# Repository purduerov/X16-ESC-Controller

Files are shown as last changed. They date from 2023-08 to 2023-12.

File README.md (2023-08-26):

# Readme for X16-ESC-Controller
This board turns signals from the Pi into PWM signals that go to the ESC Adapter

Whenever you make a new part, download the datasheet and save it here _**and**_ with the part in the parts library

Always pull other people's changes before beginning to work
`git pull`

Be sure to push your changes after  working on them. Run:
1. `git add .` to add any files in this directory or a subdirectory
or `git add -u` to add any modified files
2. (Optional) `git clean -nX` to see what ignored files can be removed
	`git clean -fX` removes ignored files (Eagle backups)
3. `git commit -m "helpful commit message"` with a description of the work that you did
4. `git push` to push your work to github

Other helpful commands
* `git status` says information about modified and staged files
* `git log` shows the recent commits of the repository
* `git log filename.extension` show the recent commits for just that file
* `git checkout first-couple-letter-of-commit-id` lets you go back to a previous version
* `git checkout master` brings you back to the latest commit
* `git tag` lists the tags
* `git tag -a orderX -m "the version of the board placed for the X'th order"` tag a specific commit
* `git push --tags` needed to push tags to remote
* `git show orderX` show the commit log for the given tag
* `git checkout orderX` go back and interact with the files at the tagged commit

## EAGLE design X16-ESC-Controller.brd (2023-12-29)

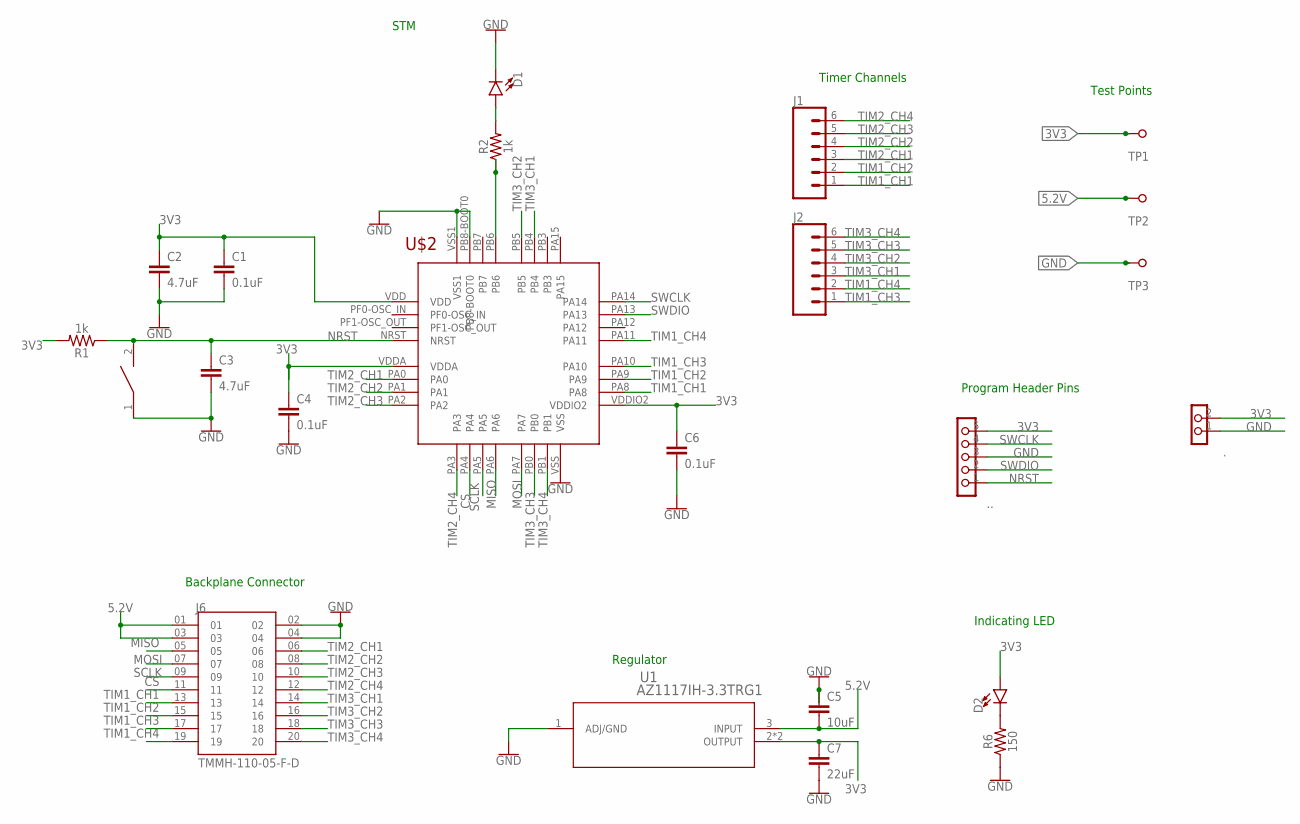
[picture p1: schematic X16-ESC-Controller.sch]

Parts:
.: TEST_PIN-1X2; 1X02
..: TEST_PIN-1X5; 1X05
C1, C4, C6: 0.1uF; 0603
C2, C3: 4.7uF; 0603
C5: 10uF; 0603
C7: 22uF; 0603
D1, D2: Green; LED-0805
J1, J2: CONN_06NO_SILK_NO_POP; 1X06_NO_SILK
J6: TMMH-110-05-F-D; SAMTEC_TMMH-110-05-F-D
R1, R2: 1k; 0603
R6: 150; 0603
TP1, TP2, TP3: TESTPOINT_5.04MM
U1: AZ1117IH-3.3TRG1; SOT223_AZ1117I_6P5X3P5_DIO
U$2: IC_STM32F042K6T6; STM32F042K6T6
U$3: SWITCH_DISCRETECOMPONENTS; DISCRETECOMPONENTS_SW_2512

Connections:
3V3: ..2, ...5, C1.1, C2.1, C4.1, C6.1, C7.1, D2.A, R1.2, TP1.TP, U1.2 (OUTPUT), U1.4 (OUTPUT), U$2.VDD, U$2.VDDA, U$2.VDDIO2
5.2V: C5.2, J6.01, J6.03, TP2.TP, U1.3 (INPUT)
CS: J6.11, U$2.PA4
GND: ..1, ...3, C1.2, C2.2, C3.2, C4.2, C5.1, C6.2, C7.2, D1.C, J6.02, J6.04, R6.1, TP3.TP, U1.1 (ADJ/GND), U$2.PB8-BOOT0, U$2.VSS, U$2.VSS1, U$3.1
MISO: J6.05, U$2.PA6
MOSI: J6.07, U$2.PA7
unnamed: D2.C, R6.2
unnamed: R2.1, U$2.PB6
unnamed: D1.A, R2.2
NRST: ...1, C3.1, R1.1, U$2.NRST, U$3.2
SCLK: J6.09, U$2.PA5
SWCLK: ...4, U$2.PA14
SWDIO: ...2, U$2.PA13
TIM1_CH1: J1.1, J6.13, U$2.PA8
TIM1_CH2: J1.2, J6.15, U$2.PA9
TIM1_CH3: J2.1, J6.17, U$2.PA10
TIM1_CH4: J2.2, J6.19, U$2.PA11
TIM2_CH1: J1.3, J6.06, U$2.PA0
TIM2_CH2: J1.4, J6.08, U$2.PA1
TIM2_CH3: J1.5, J6.10, U$2.PA2
TIM2_CH4: J1.6, J6.12, U$2.PA3
TIM3_CH1: J2.3, J6.14, U$2.PB4
TIM3_CH2: J2.4, J6.16, U$2.PB5
TIM3_CH3: J2.5, J6.18, U$2.PB0
TIM3_CH4: J2.6, J6.20, U$2.PB1

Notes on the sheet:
Timer Channels
Program Header Pins
Indicating LED
Regulator
Test Points
Backplane Connector
STM

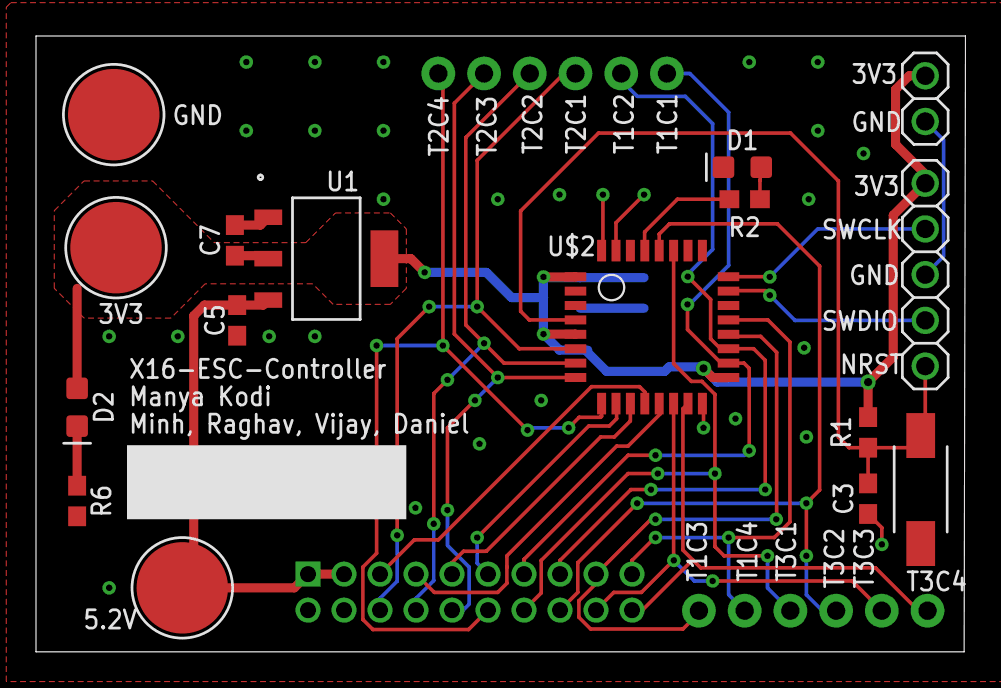
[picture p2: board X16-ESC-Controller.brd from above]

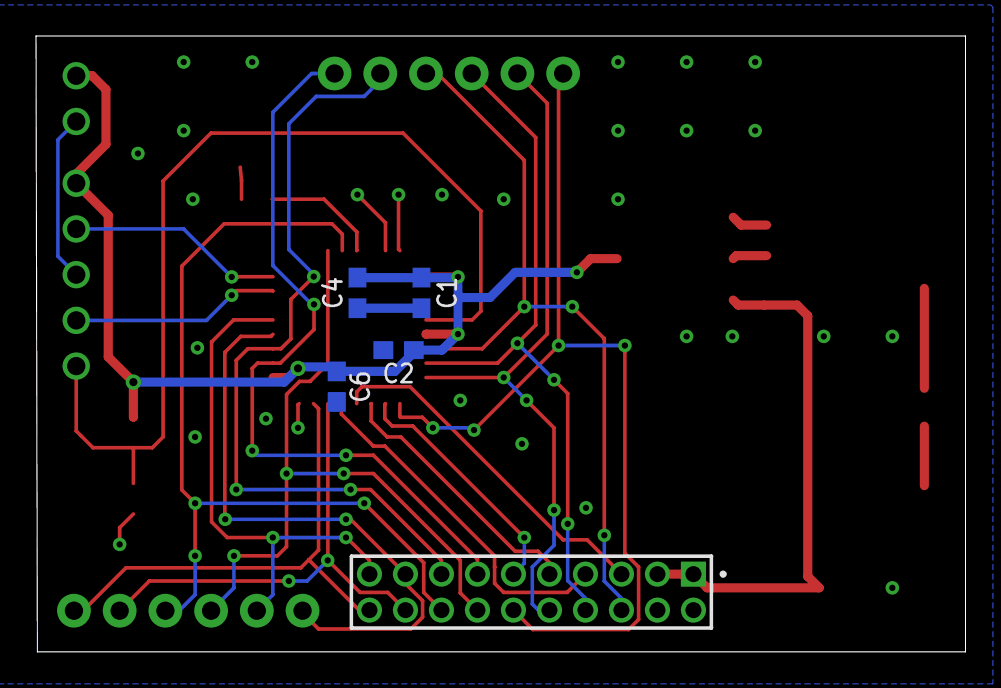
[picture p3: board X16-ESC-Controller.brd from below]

Board: 2 copper layers, 51.6 x 34.2 mm, 23 parts (5 on the bottom side), 25 nets.

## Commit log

2023-10-05 STM & Connectors
    [X16-ESC-Controller.brd, X16-ESC-Controller.sch]
2023-12-07 12/6/2023 pt2
    [X16-ESC-Controller.brd, X16-ESC-Controller.sch]
2023-12-07 12/06/2023 pt3
    [X16-ESC-Controller.brd, X16-ESC-Controller.sch]
2023-12-21 increased text size + minor changes to trace routing
    [X16-ESC-Controller.brd, X16-ESC-Controller.sch]
2023-12-23 fixed LDO thermals and pad 4, updated LDO caps to datasheet recommended, cleaned up silkscreen
    [X16-ESC-Controller.brd, X16-ESC-Controller.sch]
2023-12-29 Minh Update 1
    [X16-ESC-Controller.brd]

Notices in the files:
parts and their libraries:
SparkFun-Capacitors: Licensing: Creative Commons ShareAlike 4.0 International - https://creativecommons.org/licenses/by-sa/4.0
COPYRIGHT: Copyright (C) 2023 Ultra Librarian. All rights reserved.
